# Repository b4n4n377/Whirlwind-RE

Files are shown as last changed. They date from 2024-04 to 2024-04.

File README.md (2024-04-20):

# Whirlwind-RE
Clone / Reverse Engineering of the open source 'Whirlwind - PC to JAMMA Arcade Cabinet Interface'
- see https://www.instructables.com/Whirlwind-PC-to-JAMMA-Arcade-Cabinet-Interface/
- see https://github.com/baritonomarchetto/Whirlwind

We encountered a problem where too little voltage reached the video amp due to the voltage divider at pin 1 of the RPI2040 used for sync control.

To address this, we implemented a different sync circuit.

This is one of our very first designs. Ideas for further optimizations are very welcome.

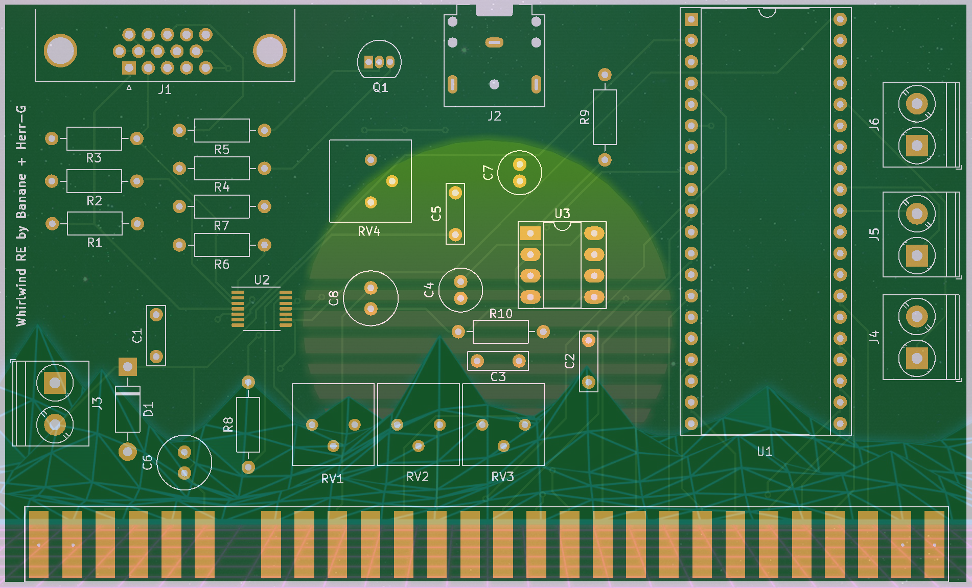
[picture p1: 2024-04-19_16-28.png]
Drag Racing

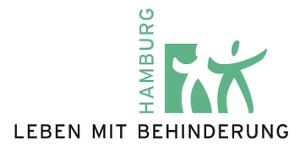
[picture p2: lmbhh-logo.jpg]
Leben mit Behinderung

Our Manufacturing Partners

***Shoutouts to** the arcade communities from **Arcade Zone** (https://forum.arcade-zone.de/index.php) and **Groovy Arcade** (https://gitlab.com/groovyarcade/support/-/wikis/home)*

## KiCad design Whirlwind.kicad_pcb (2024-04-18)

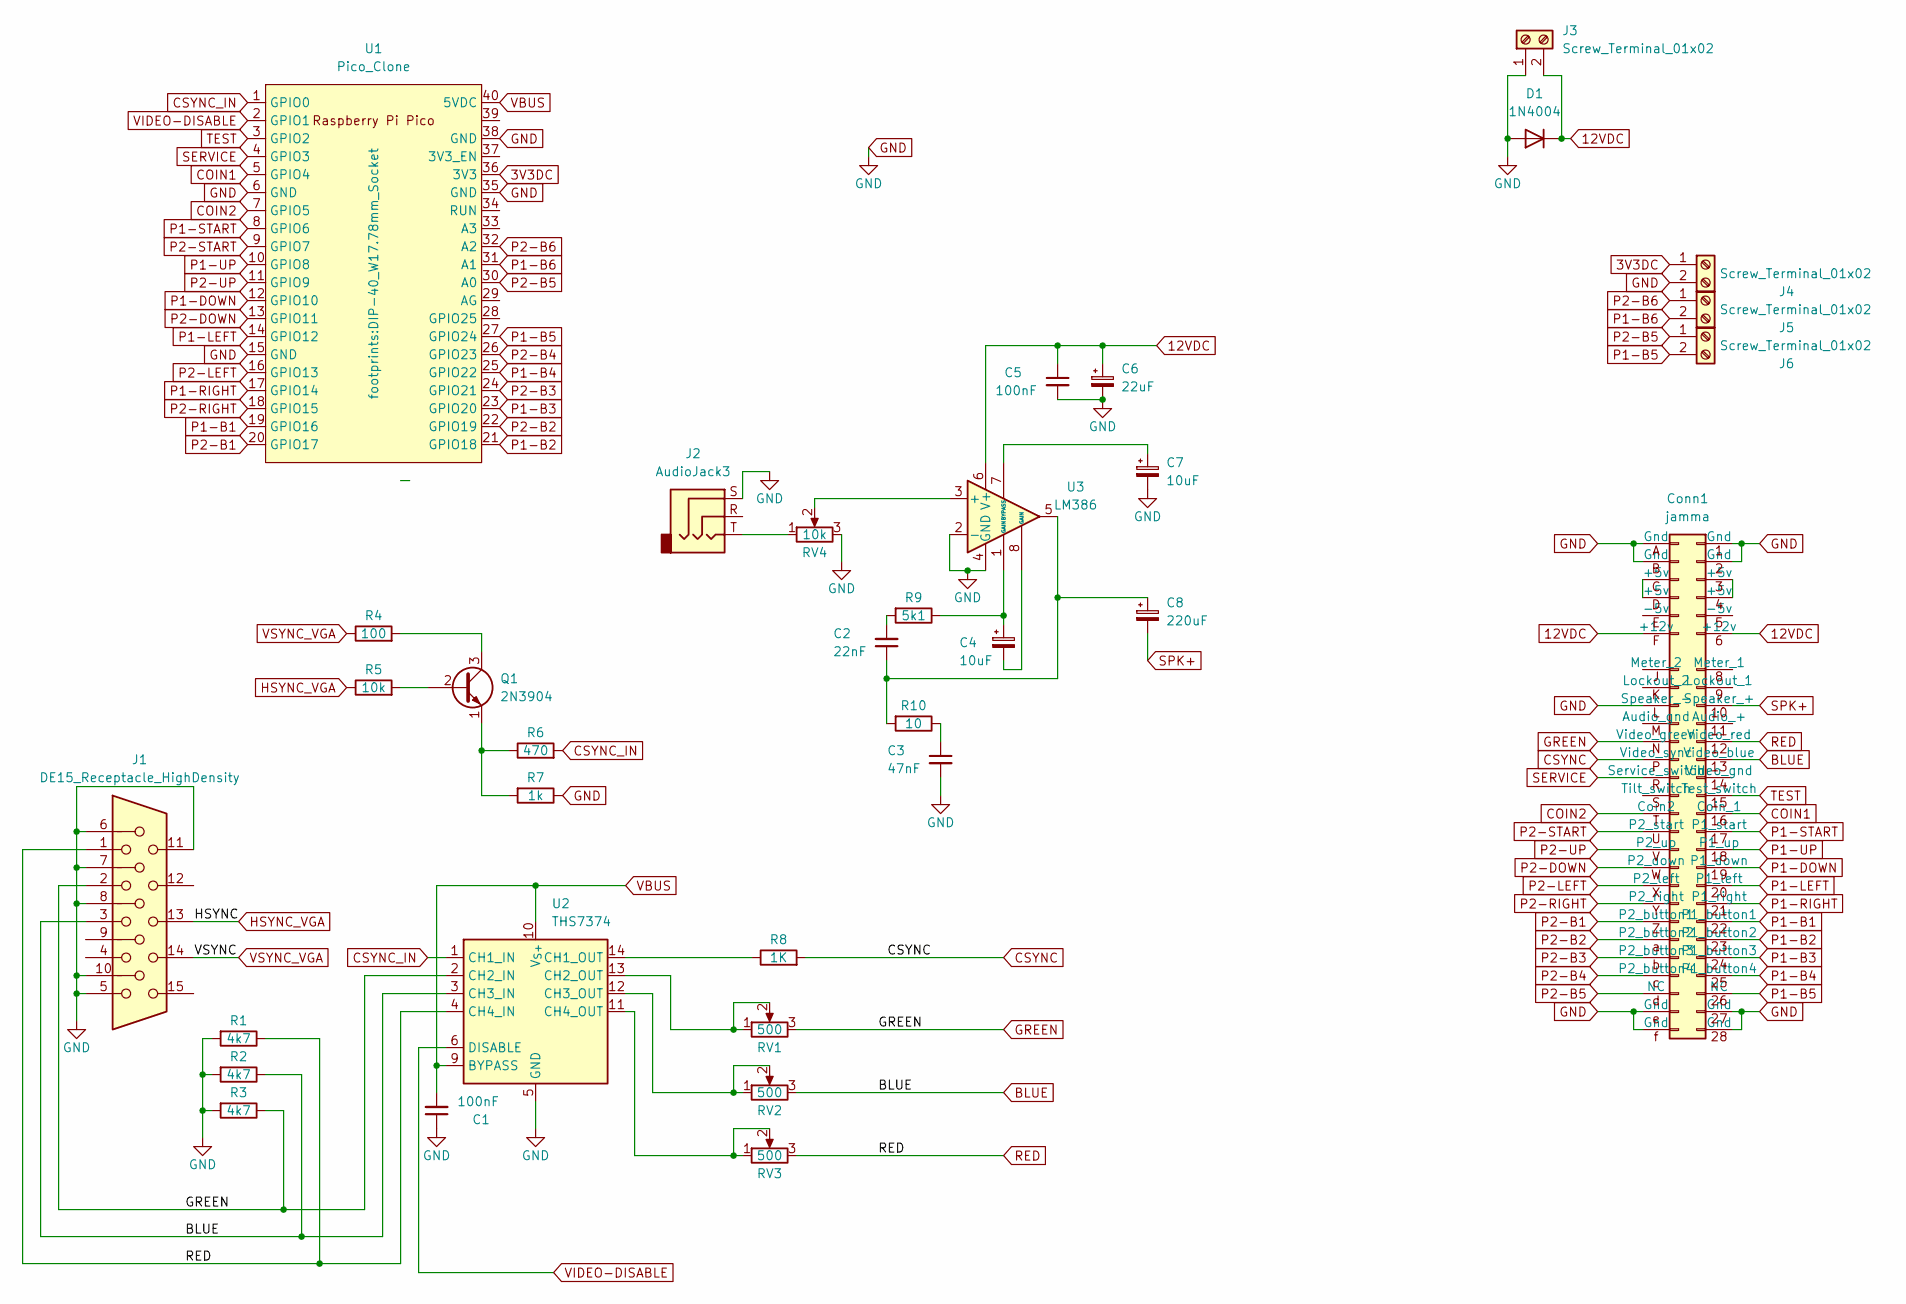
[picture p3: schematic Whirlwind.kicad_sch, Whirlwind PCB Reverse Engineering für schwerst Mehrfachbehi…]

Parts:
C1, C5: 100nF; C_Rect_L7.0mm_W2.0mm_P5.00mm
C2: 22nF; C_Rect_L7.0mm_W2.0mm_P5.00mm
C3: 47nF; C_Rect_L7.0mm_W2.0mm_P5.00mm
C4, C7: 10uF; C_Radial_D5.0mm_H11.0mm_P2.00mm
C6: 22uF; C_Radial_D6.3mm_H11.0mm_P2.50mm
C8: 220uF; C_Radial_D6.3mm_H11.0mm_P2.50mm
Conn1: jamma; JAMMA-56
D1: 1N4004; D_DO-41_SOD81_P10.16mm_Horizontal
J1: DE15_Receptacle_HighDensity; DSUB-15-HD_Female_Horizontal_P2.29x1.98mm_EdgePinOffset3.03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
J2: AudioJack3; Jack_3.5mm_CUI_SJ1-3523N_Horizontal
J3, J4, J5, J6: Screw_Terminal_01x02; TerminalBlock_Phoenix_PT-1,5-2-5.0-H_1x02_P5.00mm_Horizontal
Q1: 2N3904; TO-92_Inline
R1, R2, R3: 4k7; R_Axial_DIN0207_L6.3mm_D2.5mm_P10.16mm_Horizontal
R4: 100; R_Axial_DIN0207_L6.3mm_D2.5mm_P10.16mm_Horizontal
R5: 10k; R_Axial_DIN0207_L6.3mm_D2.5mm_P10.16mm_Horizontal
R6: 470; R_Axial_DIN0207_L6.3mm_D2.5mm_P10.16mm_Horizontal
R7: 1k; R_Axial_DIN0207_L6.3mm_D2.5mm_P10.16mm_Horizontal
R8: 1K; R_Axial_DIN0207_L6.3mm_D2.5mm_P10.16mm_Horizontal
R9: 5k1; R_Axial_DIN0207_L6.3mm_D2.5mm_P10.16mm_Horizontal
R10: 10; R_Axial_DIN0207_L6.3mm_D2.5mm_P10.16mm_Horizontal
RV1, RV2, RV3: 500; Potentiometer_Bourns_3386P_Vertical
RV4: 10k; Potentiometer_Bourns_3386P_Vertical
U1: Pico_Clone; DIP-40_W17.78mm_Socket
U2: THS7374; TSSOP-14_4.4x5mm_P0.65mm
U3: LM386; DIP-8_W7.62mm_Socket_LongPads

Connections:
3V3DC: J4.1, U1.36 (3V3)
12VDC: C5.1, C6.1, Conn1.6 (+12v), Conn1.F (+12v), D1.1 (K), J3.2, U3.6 (V+)
BLUE: Conn1.13 (Video_blue), J1.3, R2.1, RV2.3, U2.3 (CH3_IN)
COIN1: Conn1.16 (Coin_1), U1.5 (GPIO4)
COIN2: Conn1.T (Coin2), U1.7 (GPIO5)
CSYNC: Conn1.P (Video_sync), R8.2
CSYNC_IN: R6.2, U1.1 (GPIO0), U2.1 (CH1_IN)
GND: C1.1, C3.2, C5.2, C6.2, C7.2, Conn1.1 (Gnd), Conn1.2 (Gnd), Conn1.27 (Gnd), Conn1.28 (Gnd), Conn1.A (Gnd), Conn1.B (Gnd), Conn1.L (Speaker_-), Conn1.e (Gnd), Conn1.f (Gnd), D1.2 (A), J1.5, J1.6, J1.7, J1.8, J1.10, J1.11, J2.S, J3.1, J4.2, R1.2, R2.2, R3.2, R7.1, RV4.3, U1.6 (GND), U1.15 (GND), U1.35 (GND), U1.38 (GND), U2.5 (GND), U3.2 (-), U3.4 (GND)
GREEN: Conn1.N (Video_green), J1.2, R3.1, RV1.3, U2.2 (CH2_IN)
HSYNC_VGA: J1.13, R5.1
unnamed: C2.1, C8.1, R10.2, U3.5
unnamed: C2.2, R9.2
unnamed: C3.1, R10.1
unnamed: C4.1, R9.1, U3.1 (GAIN)
unnamed: C4.2, U3.8 (GAIN)
unnamed: Conn1.3 (+5v), Conn1.4 (+5v)
unnamed: Conn1.C (+5v), Conn1.D (+5v)
unnamed: J2.T, RV4.1
unnamed: Q1.2 (B), R5.2
unnamed: Q1.3 (C), R4.2
unnamed: Q1.1 (E), R6.1, R7.2
unnamed: R8.1, U2.14 (CH1_OUT)
unnamed: RV1.1, RV1.2, U2.13 (CH2_OUT)
unnamed: RV2.1, RV2.2, U2.12 (CH3_OUT)
unnamed: RV3.1, RV3.2, U2.11 (CH4_OUT)
unnamed: RV4.2, U3.3 (+)
unnamed: C7.1, U3.7 (BYPASS)
P1-B1: Conn1.22 (P1_button1), U1.19 (GPIO16)
P1-B2: Conn1.23 (P1_button2), U1.21 (GPIO18)
P1-B3: Conn1.24 (P1_button3), U1.23 (GPIO20)
P1-B4: Conn1.25 (P1_button4), U1.25 (GPIO22)
P1-B5: Conn1.26 (NC), J6.2, U1.27 (GPIO24)
P1-B6: J5.2, U1.31 (A1)
P1-DOWN: Conn1.19 (P1_down), U1.12 (GPIO10)
P1-LEFT: Conn1.20 (P1_left), U1.14 (GPIO12)
P1-RIGHT: Conn1.21 (P1_right), U1.17 (GPIO14)
P1-START: Conn1.17 (P1_start), U1.8 (GPIO6)
P1-UP: Conn1.18 (P1_up), U1.10 (GPIO8)
P2-B1: Conn1.Z (P2_button1), U1.20 (GPIO17)
P2-B2: Conn1.a (P2_button2), U1.22 (GPIO19)
P2-B3: Conn1.b (P2_button3), U1.24 (GPIO21)
P2-B4: Conn1.c (P2_button4), U1.26 (GPIO23)
P2-B5: Conn1.d (NC), J6.1, U1.30 (A0)
P2-B6: J5.1, U1.32 (A2)
P2-DOWN: Conn1.W (P2_down), U1.13 (GPIO11)
P2-LEFT: Conn1.X (P2_left), U1.16 (GPIO13)
P2-RIGHT: Conn1.Y (P2_right), U1.18 (GPIO15)
P2-START: Conn1.U (P2_start), U1.9 (GPIO7)
P2-UP: Conn1.V (P2_up), U1.11 (GPIO9)
RED: Conn1.12 (Video_red), J1.1, R1.1, RV3.3, U2.4 (CH4_IN)
SERVICE: Conn1.R (Service_switch), U1.4 (GPIO3)
SPK+: C8.2, Conn1.10 (Speaker_+)
TEST: Conn1.15 (Test_switch), U1.3 (GPIO2)
VBUS: C1.2, U1.40 (5VDC), U2.9 (BYPASS), U2.10 (V_{S+})
VIDEO-DISABLE: U1.2 (GPIO1), U2.6 (DISABLE)
VSYNC_VGA: J1.14, R4.1

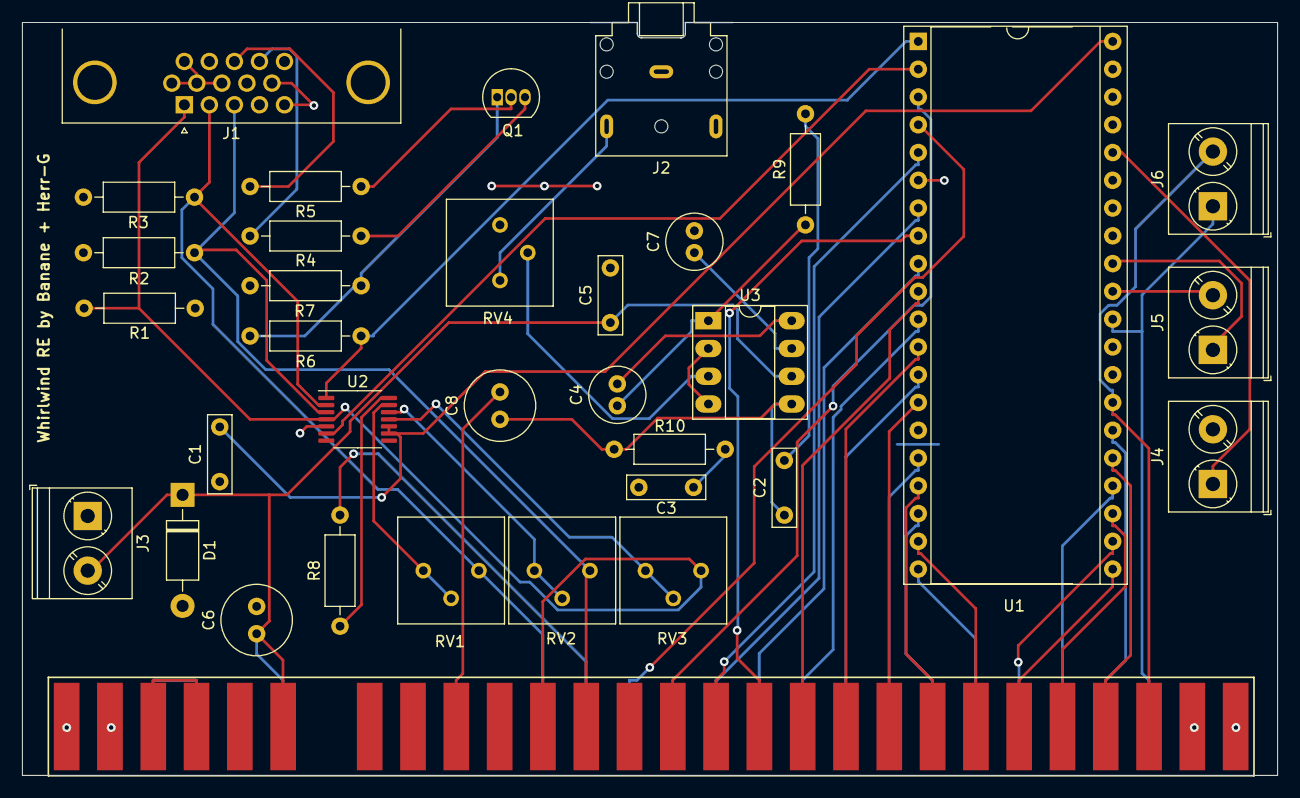
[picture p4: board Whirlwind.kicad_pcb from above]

Board: 2 copper layers, 114.8 x 68.9 mm, 34 parts (0 on the bottom side), 56 nets.
